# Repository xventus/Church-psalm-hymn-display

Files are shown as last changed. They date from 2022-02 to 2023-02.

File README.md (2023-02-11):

# Church psalm hymn display, display unit

Project for displaying hymn numbers and lyrics. This is the latest version and cheaper variant of the original FPGA VGA version. Solution based on a VGA LCD display and a remote keyboard with wireless / wired connection. Here are the complete resources including schematics and links to the modules. 

The old types of displays based on LED displays are compatible, the transmission protocol has not changed. 

# Číselník a zpěvník do kostelů

Jde o inovaci původní verze číselníku s LED i FPGA VGA zobrazovači. Protokol je zpětně kompatibilní. 
Zobrazovač je založen na VGA LCD monitoru a vzdáleného ovladače. Projekt je koncipován tak, aby jej byl schopen kdokoliv replikovat za pomocí dostupných modulů Arduino / ESP32 a nemusel vytvářet vlastní DPS.

VGA zobrazovač je založen na ESP32, konkretně levném modulu LILYGO® TTGO VGA32 V1.4  (s SD kartou)
http://www.lilygo.cn/prod_view.aspx?TypeId=50033&Id=1083

Klávesnici lze připojit buď lokálně přímo k TTGO VGA32 (PS/2), nebo přes vzdáleně přes RF modul, popřípadě RS485.
RF/RS modul se připojuje na PS/2 Mouse konektor Data (27).  

Vzdálená klávesnice je založena na ATMEGA328 v základním zapojení s 16MHz krystalem. Schéma a PCB design přiložen. Popřípadě lze použít jakékoliv Arduino. 
Oproti původní verzi nepoužívá modul MAX3421, ale využívá možnosti některých USB klávesnic pracovat v režimu PS/2. Pro zobrazení zadávaného čísla se používá modul LED displeje založený na TM1637. Pro bezdrátovou komunikaci lze využít modul APC 220. 

Kompatibilní klávesnice např. CONNECT IT NumCALC CKB-0060-BK
Nekompatibilní např. Genius NumPad i110

# Data pro SD kartu

Adresář scripts obsahuje pomocné programy pro převod žalmů a kancionálu do formátu pro VGA displej. 
Data z kancinálu byla získána stažením obsahu webu www.kancional.cz a převodem z html do vlastních dat. 
Texty žalmů jsou opisem z příšlušných knih. 

# Režimy zobrazení

V základním režimu zobrazovač nahrazuje tříciferný zobrazovač (000-996) s možností zobrazení slok (1-9).
Pokud má ESPšě modul připojenou SD kartu, lze zobrazovat žalmy, popřípadě i texty z kancionálu. 

Nastavemní viz. /doc/user-manual-csy.pdf 

# Licence

Volně k použití pro kostely, nekomerční účely ...

# Pár obrázků
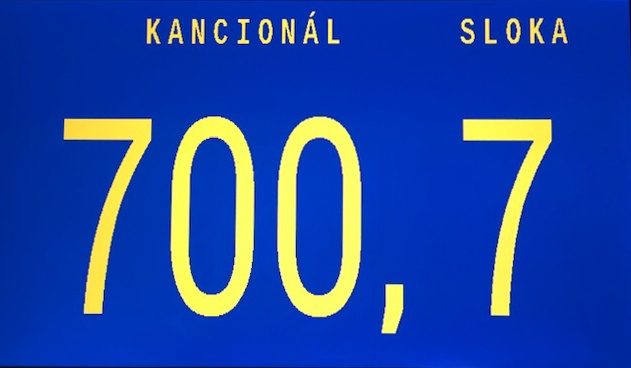
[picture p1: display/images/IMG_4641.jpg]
screen

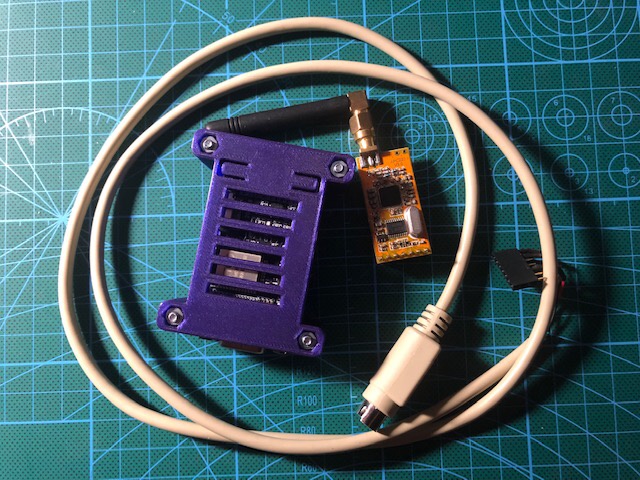
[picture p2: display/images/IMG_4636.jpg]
main board

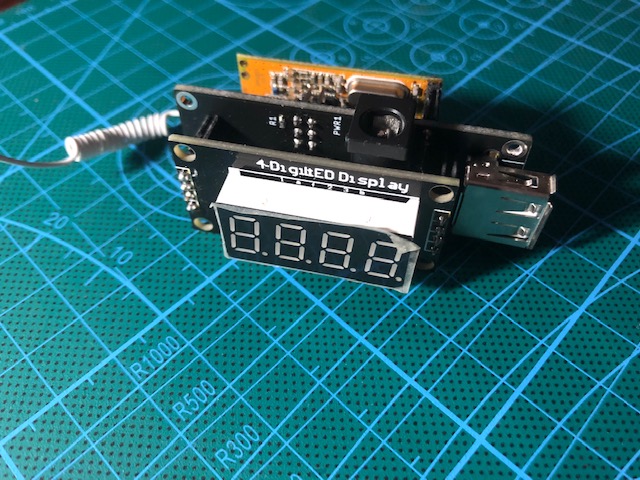
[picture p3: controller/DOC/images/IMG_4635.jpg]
remote

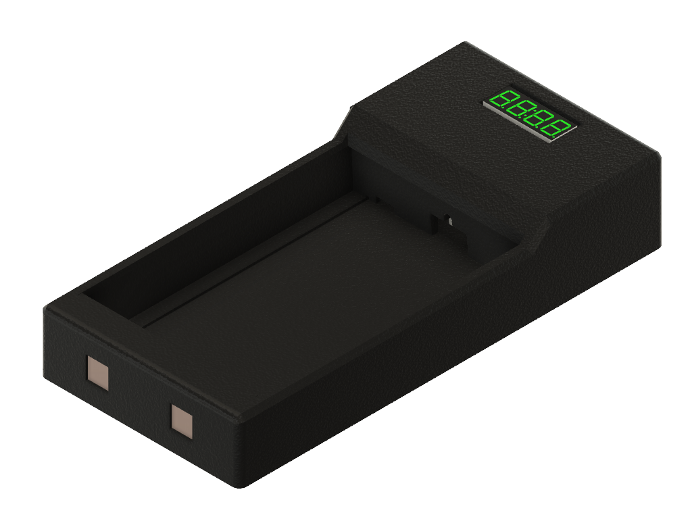
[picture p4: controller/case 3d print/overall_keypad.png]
case


# Nastavení knihoven
```
Platform espressif32 @ 6.0.1 (required: espressif32)
├── framework-arduinoespressif32 @ 3.20006.221224 (required: platformio/framework-arduinoespressif32 @ ~3.20006.0)
├── tool-esptoolpy @ 1.40400.0 (required: platformio/tool-esptoolpy @ ~1.40400.0)
├── tool-mkfatfs @ 2.0.1 (required: platformio/tool-mkfatfs @ ~2.0.0)
├── tool-mklittlefs @ 1.203.210628 (required: platformio/tool-mklittlefs @ ~1.203.0)
├── tool-mkspiffs @ 2.230.0 (required: platformio/tool-mkspiffs @ ~2.230.0)
├── tool-openocd-esp32 @ 2.1100.20220706 (required: platformio/tool-openocd-esp32 @ ~2.1100.0)
└── toolchain-xtensa-esp32 @ 8.4.0+2021r2-patch5 (required: espressif/toolchain-xtensa-esp32 @ 8.4.0+2021r2-patch5)

Libraries
└── FabGL @ 1.0.9 (required: fdivitto/FabGL @ ^1.0.9)
```

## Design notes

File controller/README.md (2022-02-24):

# controller

Remote control for the display. The controller is based on atmega328p. For its operation it requires a connected numeric keypad, which communicates via PS/2 and is connected to USB. Not all USB numeric keyboards can communicate this way. 

The DOC directory contains the schematic and STL for the box. 

Other libraries are used:

SevenSegmentTM1637 - see lib/SevenSegmentTM1637 for link and description.

PS2KeyAdvanced - see lib/PS2KeyAdvanced for link and description

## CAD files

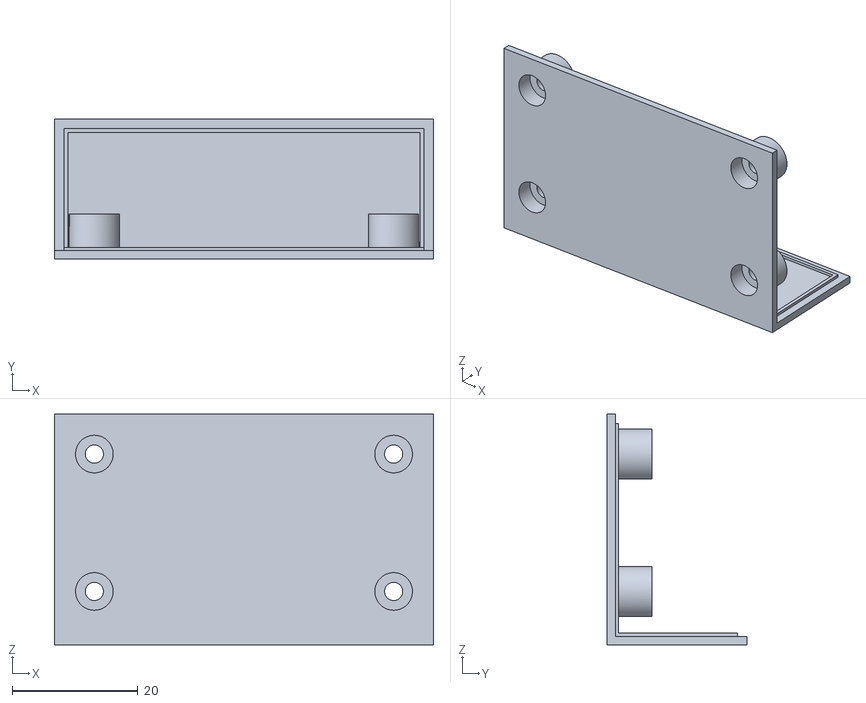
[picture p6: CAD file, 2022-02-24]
controller/case 3d print/charger_cover.stl
60.4 x 22.4 x 36.8

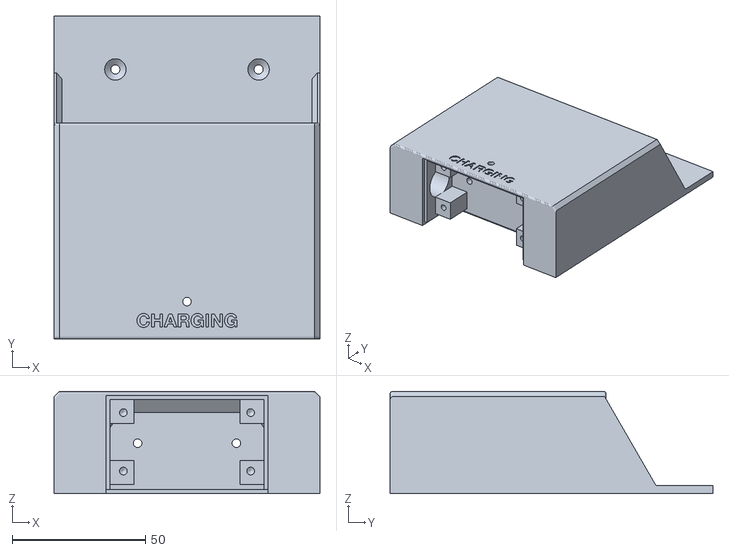
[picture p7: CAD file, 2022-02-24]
controller/case 3d print/charger_base.stl
99.7 x 121.0 x 38.4

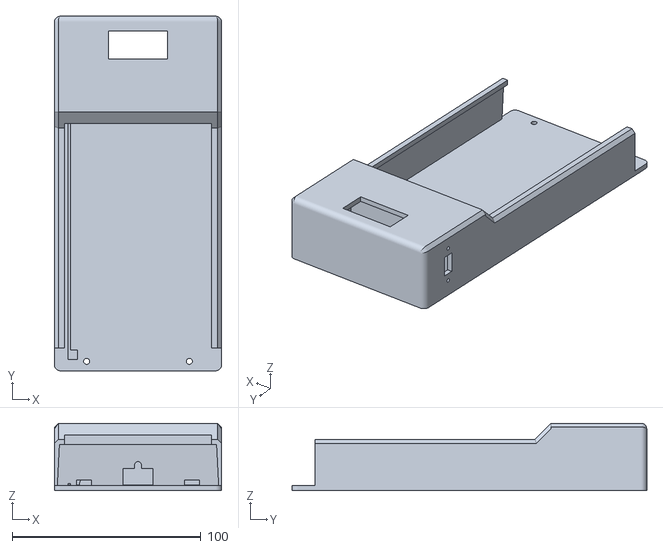
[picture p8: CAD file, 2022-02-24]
controller/case 3d print/Base.stl
88.4 x 187.7 x 35.7

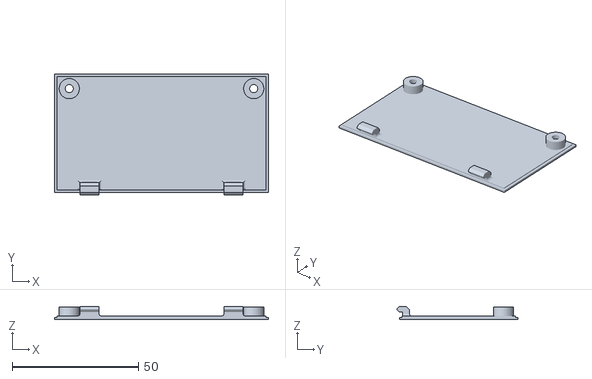
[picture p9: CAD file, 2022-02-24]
controller/case 3d print/Lid.stl
84.7 x 48.0 x 5.20

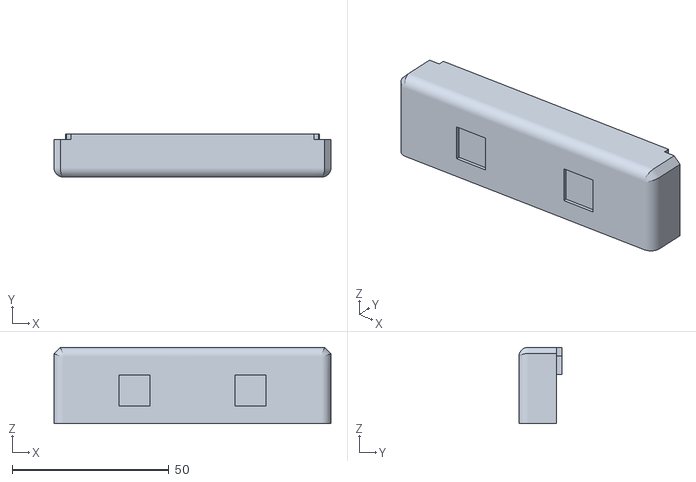
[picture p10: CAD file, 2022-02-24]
controller/case 3d print/Enclousure.stl
88.4 x 13.8 x 24.4

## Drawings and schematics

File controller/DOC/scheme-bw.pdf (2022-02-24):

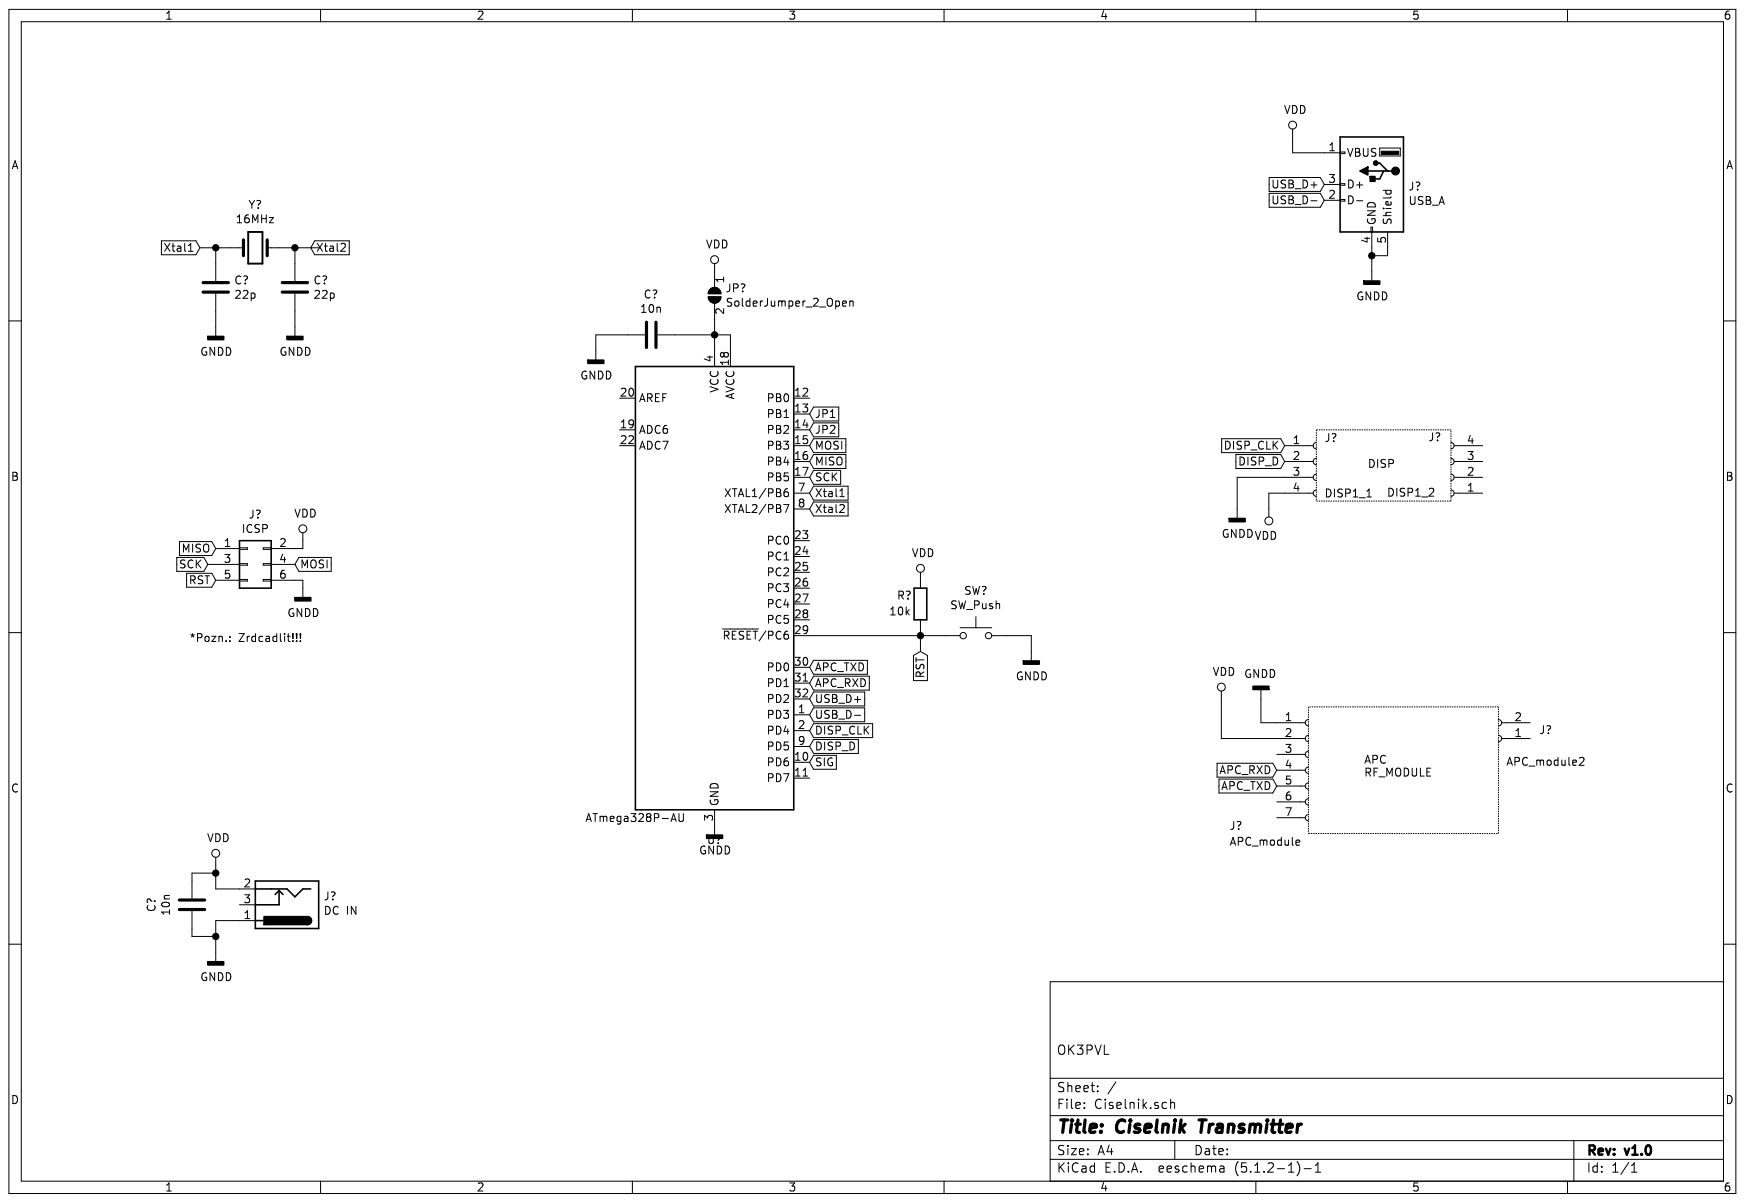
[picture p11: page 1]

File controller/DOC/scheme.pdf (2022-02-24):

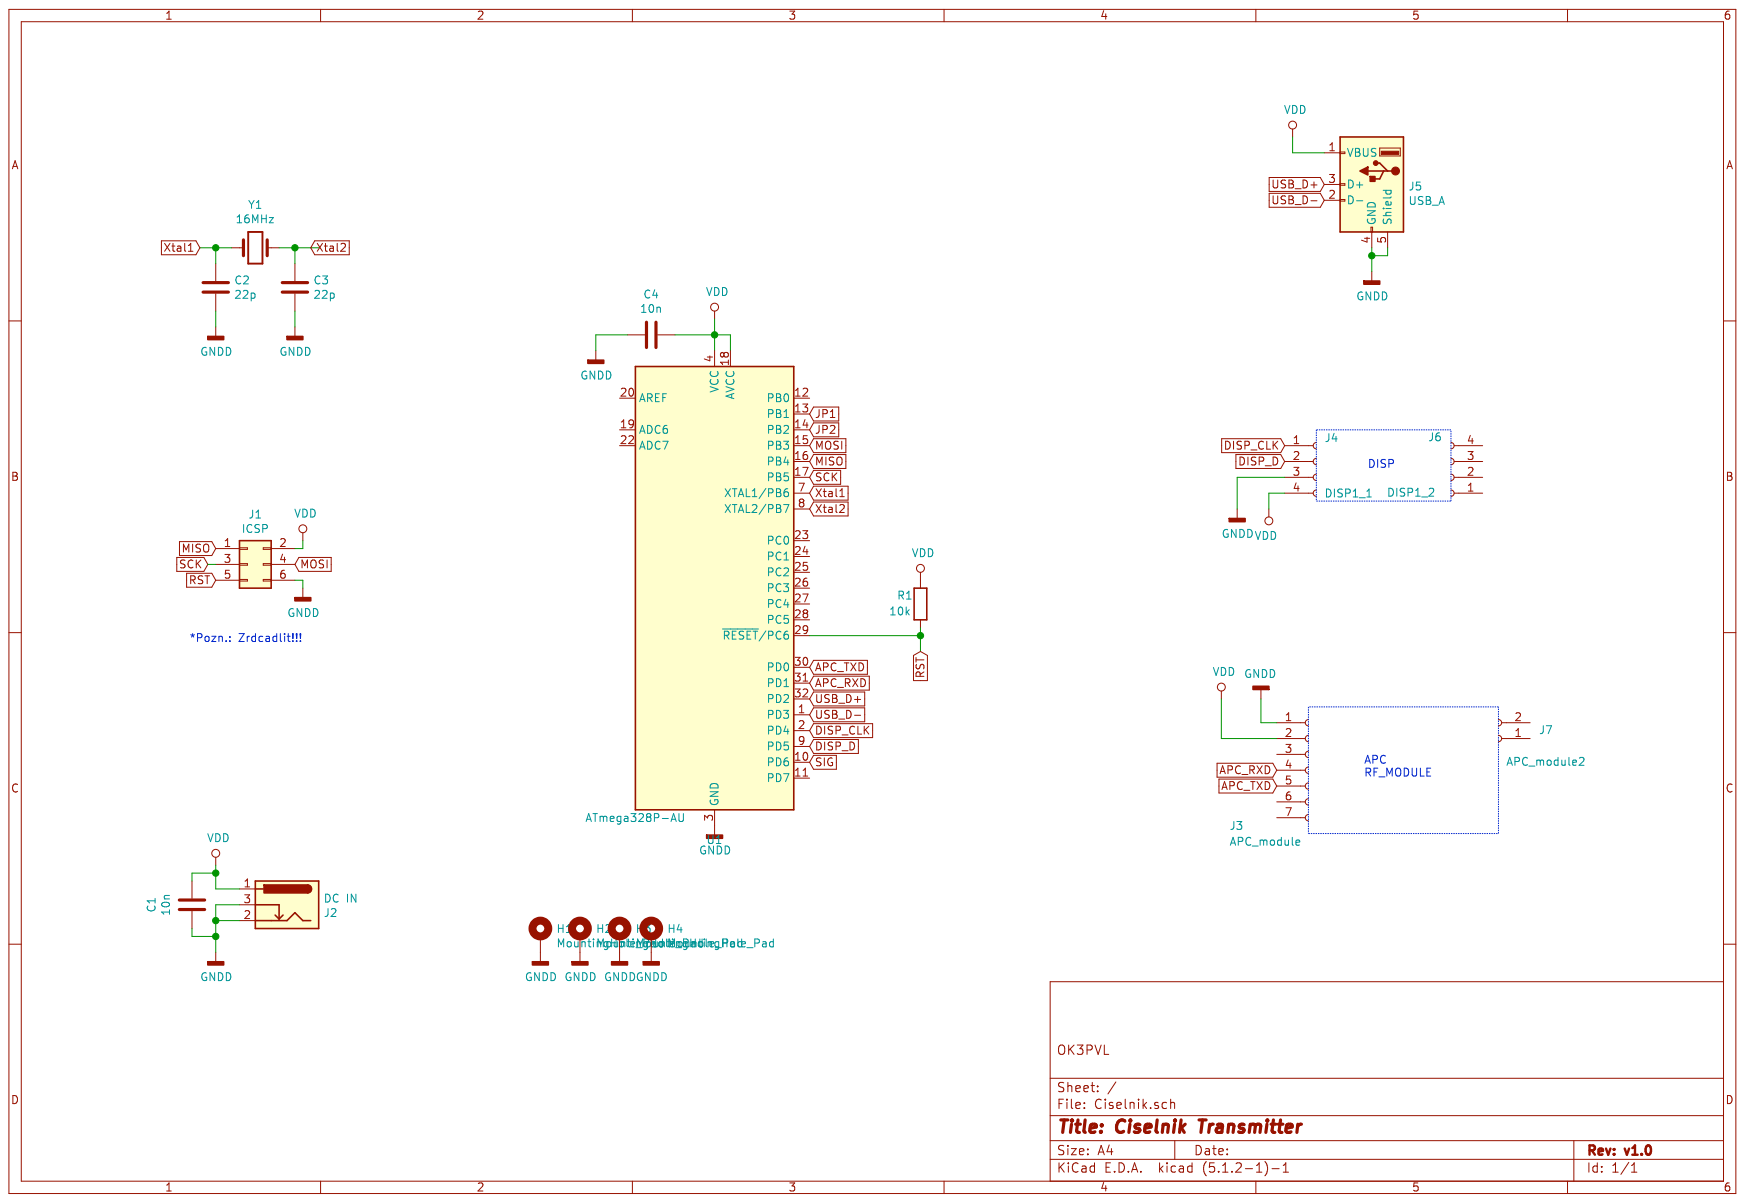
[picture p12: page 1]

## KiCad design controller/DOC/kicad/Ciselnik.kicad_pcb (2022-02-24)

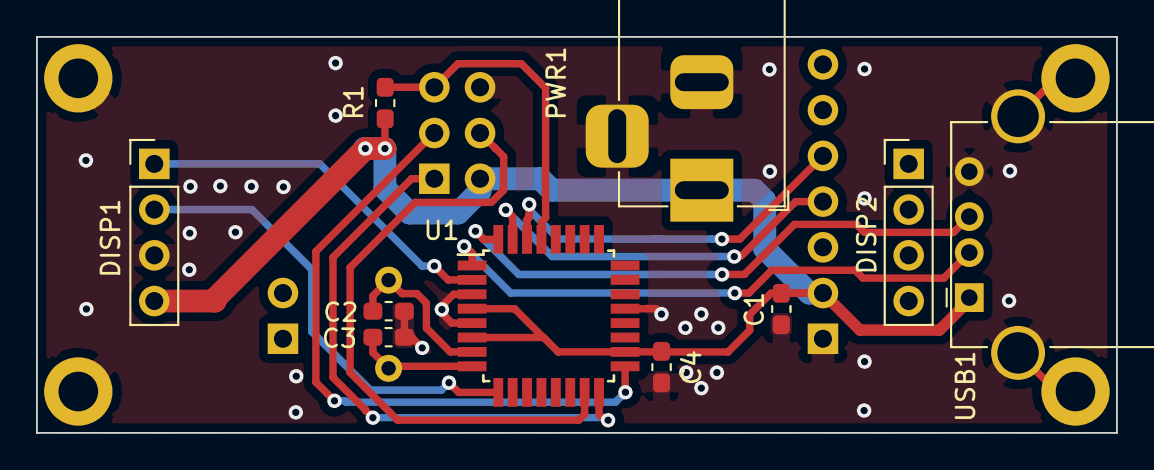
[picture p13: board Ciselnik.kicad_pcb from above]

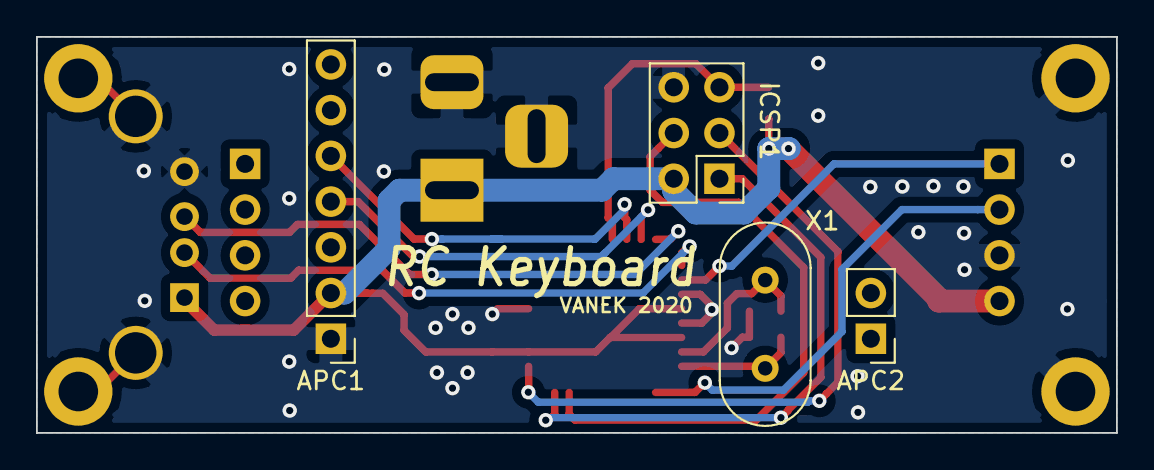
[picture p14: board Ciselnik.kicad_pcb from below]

Board: 2 copper layers, 60.0 x 22.0 mm, 18 parts (4 on the bottom side), 14 nets.

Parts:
APC1: APC_module; PinHeader_1x07_P2.54mm_Vertical
APC2: APC_module2; PinHeader_1x02_P2.54mm_Vertical
C1, C4: 10n; C_0603_1608Metric_Pad1.05x0.95mm_HandSolder
C2, C3: 22p; C_0603_1608Metric_Pad1.05x0.95mm_HandSolder
DISP1: DISP1_1; PinHeader_1x04_P2.54mm_Vertical
DISP2: DISP1_2; PinHeader_1x04_P2.54mm_Vertical
H1, H2, H3, H4: MountingHole_Pad; MountingHole_2.2mm_M2_DIN965_Pad
ICSP1: ICSP; PinHeader_2x03_P2.54mm_Vertical
PWR1: DC IN; BarrelJack_Horizontal
R1: 10k; R_0603_1608Metric_Pad1.05x0.95mm_HandSolder
U1: ATmega328P-AU; TQFP-32_7x7mm_P0.8mm
USB1: USB_A; USB_A_Stewart_SS-52100-001_Horizontal
X1: 16MHz; Crystal_HC18-U_Vertical

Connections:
APC_RXD: APC1.4, U1.31
APC_TXD: APC1.5, U1.30
DISP_CLK: DISP1.1, U1.2
DISP_D: DISP1.2, U1.9
GNDD: APC1.1, C1.1, C2.2, C3.2, C4.1, DISP1.3, H1.1, H2.1, H3.1, H4.1, ICSP1.6, PWR1.2, PWR1.3, U1.3, U1.5, U1.21, USB1.4, USB1.5
MISO: ICSP1.1, U1.16
MOSI: ICSP1.4, U1.15
RST: ICSP1.5, R1.1, U1.29
SCK: ICSP1.3, U1.17
USB_D+: U1.32, USB1.3
USB_D-: U1.1, USB1.2
VDD: APC1.2, C1.2, C4.2, DISP1.4, ICSP1.2, PWR1.1, R1.2, U1.4, U1.6, U1.18, USB1.1
Xtal1: C2.1, U1.7, X1.2
Xtal2: C3.1, U1.8, X1.1

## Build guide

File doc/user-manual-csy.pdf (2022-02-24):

# Číselník

Zobrazovač při zapnutí kontroluje obsah SD karty a zobrazí počet volných a obsazených mega bajtů karty, následně počet záznamů žalmu a záznamů z kancionálu. V případě, že karta je porušená nebo není vložená, napíše zobrazovač text "SD karta nenalezena". V takovém případě lze zobrazovat pouze čísla z kancionálu a žalmy nebo text z kancionálu není přístupný.
Po zobrazení konfigurace po 3 sekundách se zobrazí prázdná obrazovka s odkazem na farní stránky. Zobrazovač je připraven k příjmu zadávání údajů.
Zobrazovač může být nakonfigurován ve dvou režimech. Prvním z nich je zobrazování textu z kancionálu (pokud je uložen na SD kartě) a druhý je zobrazení pouze číselné informace. To, jaký režim je zapnut se zobrazí při startu zobrazovače ("Kancionál text: ZAPNUTO" nebo "Kancionál text: VYPNUTO").
Text z kancionálu v případě písně až po zadání čísla sloky. V případě modlitby se zobrazí ihned. Např. zadáme píseň 701 a stiskneme ENTER. Zobrazí se číslo písně z kancionálu. Pak stiskem "+" zobrazíme první sloku. Opakovaným stiskem zobrazujeme následné sloky, tak dlouho dokud jsou k dispozici. V případě, že žádná další sloka již není k dispozici, se zobrazí číslo písně a číslo sloky. Bez ohledu jaký režim je nastaven, číselník je ovládán stále stejně.

## Změna konfigurace zobrazovače

Při změně nastavení je nutné aby byly zapnuty všechny zobrazovače. Lze konfigurovat barevné schéma a nastavení zobrazování textu z kancionálu. Konfigurace je stále platná do další změny. Není ji potřeba při každém zapnutí provádět.

Klávesa | význam
0 - 9 | zadávání čísla z kancionálu nebo pořadového čísla žalmu
ENTER | odeslání čísla textu-písně z kancionálu na zobrazovač
/ (lomítko) | odeslání textu žalmu na zobrazovač
+ (plus) | sloka písně o jednu vpřed
- (mínus) | sloka písně o jednu vzad
* (hvězdička) | smazání zobrazovače
<- Backspace | smazání zadaných číslic bez odeslání (např. při chybném zadávání před odesláním)
. (tečka) | oddělovač sloky písně

Změn konfigurace se provádí odesláním čísel 999 a jako poslední číslo je nastavení konfigurace. Kód se nepotvrzuje pomocí ENTER. Při příjmu zobrazovač 3x za sebou zobrazí nastavenou konfiguraci a přejde do výchozího režimu pro příjem.

zadaný kód

9990 Kancionál text: VYPNUTO

9991 Kancionál text: ZAPNUTO

9992 Barevné schema 0, modré pozadí, žlutý text

9993 Barevné schema 1, černé pozadí, bílý text

9994 Barevné schema 2, bílé pozadí, černý text

9995 - 9999 | Vyhrazeno pro budoucí rozšíření

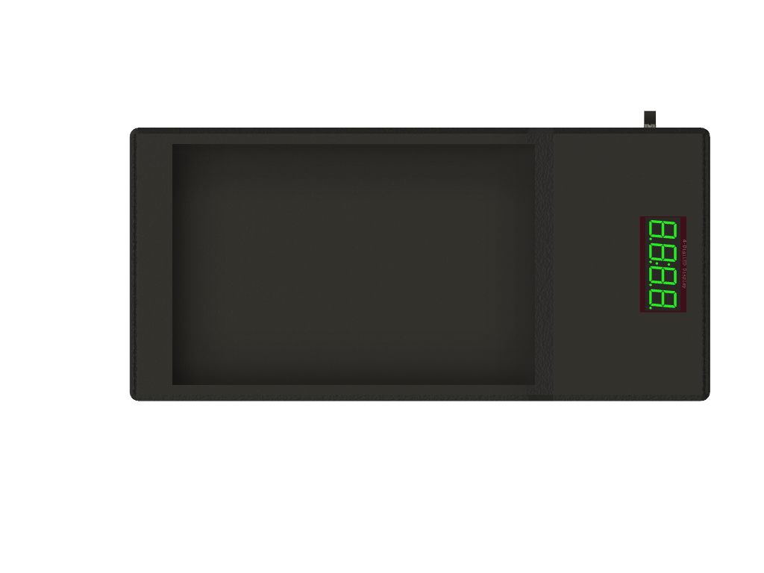
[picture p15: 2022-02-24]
controller/case 3d print/front.png

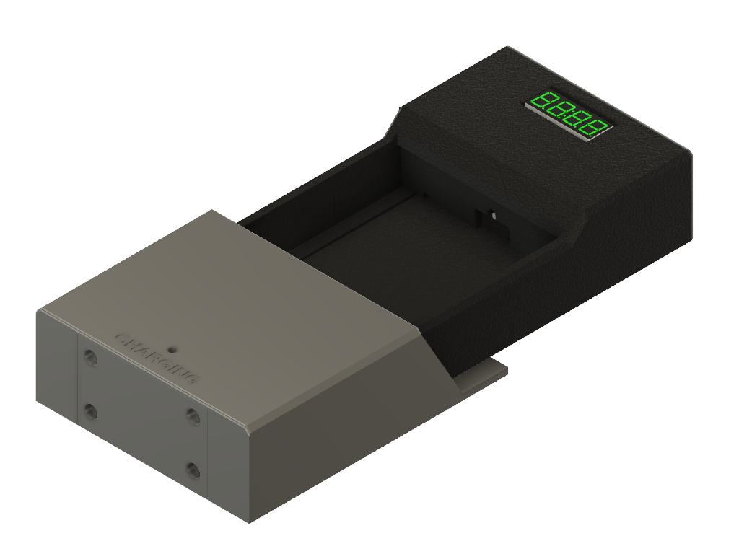
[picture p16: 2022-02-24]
controller/case 3d print/overall view.png

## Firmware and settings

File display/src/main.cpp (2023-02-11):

//
// vim: ts=4 et
// Church psalm hymn display, display unit
// Copyright (c) 2019 Petr Vanek, petr@fotoventus.cz
//
/// @file   main.cpp
/// @author Petr Vanek

/*
 based on board:  LILYGO® TTGO VGA32 V1.4 Controller PS/2 Mouse And Keyboard Graphics Library Game Engine And ANSI/VT Terminal For The ESP32
 Enviroment: ESP32 DEV Module
 L
 ibrary:   fabgle from http://www.fabglib.org/
*/

#include <stdio.h>

#include <fabgl.h>

#include "defs.h"          // constants and definitions
#include "configuration.h" // EEPROM config
#include "fonts.h"         // font glyphs
#include "net_buffer.h"    // buffer operations
#include "convertors.h"    // CSY char convertor, virtual keys to number
#include "strings_def.h"   // strings

// TODO: 
//  - move strings to program memory!!!
//  - divide the program into functional units
//  - fill in missing characters in the national alphabet

/************************************************/
// signletons

// VGA controller
fabgl::VGA16Controller VGAController;

// PS/2 keyboard as local controller
fabgl::PS2Controller PS2Controller;

// HW serial for APC220/RS485 - used only one WAY communication - RX used only
// used with remote controller via APC220 or RS485
HardwareSerial hwSerial_1(1);
NetBuffer nb;
Configuration conf;

//--------------------------------------------------------------------------------------------------------------------------------

/**
 * @brief display clear and set default color
 *
 */
void clear()
{
  Canvas cv(&VGAController);
  if (conf.getColorSchema() == 0)
  {
    cv.setPenColor(PENCOLOR);
    cv.setBrushColor(BRUSHCOLOR);
  }

  if (conf.getColorSchema() == 1)
  {
    cv.setPenColor(PENCOLOR_1);
    cv.setBrushColor(BRUSHCOLOR_1);
  }

  if (conf.getColorSchema() == 2)
  {
    cv.setPenColor(PENCOLOR_2);
    cv.setBrushColor(BRUSHCOLOR_2);
  }

  cv.clear();
}

//--------------------------------------------------------------------------------------------------------------------------------

/**
 * @brief display number at position
 *
 * @param x
 * @param y
 * @param number
 * @param fill
 */
void displayDigit(int x, int y, byte number, bool fill)
{
  Canvas cv(&VGAController);
  if (number > 10)
    return;
  cv.setGlyphOptions(GlyphOptions().FillBackground(fill).DoubleWidth(0));
  cv.drawGlyph(x, y, fontwidth, fontheight, &fontBB[0 + number][0]);
}

//--------------------------------------------------------------------------------------------------------------------------------

/**
 * @brief displays the glyph in the given size at the position
 * 
 * @param big  switches the size set 
 * @param x    position x
 * @param y    position y 
 * @param chr  desired character
 */
void displayChar(byte big, int x, int y, unsigned char chr)
{
  Canvas cv(&VGAController);
  auto decodedto = charConvertor(chr);

  if (big == 2)
  {
    cv.setGlyphOptions(GlyphOptions().FillBackground(false).DoubleWidth(1));
    cv.drawGlyph(leftsidetxt + x, topsidetxt + y, 24, 32, &fontB[decodedto][0]);
  }
  else if (big == 1)
  {
    cv.setGlyphOptions(GlyphOptions().FillBackground(false).DoubleWidth(2));
    cv.drawGlyph(leftsidetxt + x, topsidetxt + y, 24, 32, &fontB[decodedto][0]);
    cv.setGlyphOptions(GlyphOptions().FillBackground(false).DoubleWidth(3));
    cv.drawGlyph(leftsidetxt + x, topsidetxt + y + 32, 24, 32, &fontB[decodedto][0]);
  }
  else
  {
    cv.setGlyphOptions(GlyphOptions().FillBackground(false).DoubleWidth(0));
    cv.drawGlyph(leftsidetxt + x, topsidetxt + y, 24, 32, &fontB[decodedto][0]);
  }
}

//--------------------------------------------------------------------------------------------------------------------------------

/**
 * @brief prints a string at a given position in a given size
 * 
 * @param big switches the size set 
 * @param str string to print
 * @param pos 
 * @param yzero 
 * @param correction 
 * @return int 
 */
int printAtPos(byte big, const char *str, int pos, int yzero, bool correction)
{

  int x = pos;      // x possition of char
  int y = 0;        // y possiont of char
  int line = 0;     // line counter
  byte counter = 0; // char counter

  if (str == nullptr)
    return 0;
  Canvas cv(&VGAController);

  auto maxperline = (big == 1 || big == 2) ? (cv.getWidth() / (charwidthtxt * 2)) : (cv.getWidth() / charwidthtxt);
  auto linesperpage = (big == 1) ? (cv.getHeight() / (charheighttxt * 2)) : (cv.getHeight() / charheighttxt);
  if (big == 1) {
    linesperpage++;
  }
  counter = pos / (charwidthtxt + ((big == 1 || big == 2) ? charwidthtxt : 0));

  if (yzero != 0)
  {
    auto a = charheighttxt;
    a += ((big == 1) ? heightincrementcorrection : 0);
    y = a * yzero;
    linesperpage = linesperpage - yzero;
  }

  const char *st = str;
  auto cntline = (strlen(st) / maxperline) + 1;
  auto movy = charheighttxt;
  movy += ((big == 1) ? heightincrementcorrection : 0);
  auto ycorrection = (correction) ? ((linesperpage / cntline) * movy / cntline) : 0;
  if (cntline >= 7 && big == 2)
    ycorrection = 0;
  if (correction && cntline < 3)
  {
    // only y position of first line
    y += movy;
  }

  while (*st != 0)
  {

    if (*st == '\n')
    {
      // new line
      line++;
      x = 0;
      y += charheighttxt;
      y += ((big == 1) ? heightincrementcorrection : 0);
      counter = 0;
      st++;
      continue;
    }

    displayChar(big, x, y, *st);
    counter++;

    if (counter >= maxperline)
    {
      // move to next line if number of chars per line was exceeded
      line++;

      if (linesperpage <= line)
      {
        break;
      }

      // sets new position of char on the next line
      x = 0;
      y += charheighttxt;
      y += ((big == 1) ? heightincrementcorrection : 0);
      y += ycorrection;
      counter = 0;
    }
    else
    {
      x += charwidthtxt;
      x += ((big == 1 || big == 2) ? charwidthtxt : 0);
    }

    st++;
  }

  return x;
}

//--------------------------------------------------------------------------------------------------------------------------------

/**
 * @brief print from the begining
 * 
 * @param big 
 * @param str 
 * @param correction 
 */
void printAt(byte big, const char *str, bool correction)
{
   printAtPos(big, str, 0, 0, correction);
}

//--------------------------------------------------------------------------------------------------------------------------------

/**
 * @brief Printing the number
 * 
 * @param one 
 * @param two 
 * @param big 
 * @param str 
 * @param correction 
 */
void printAtWithNumber(int one, int two, byte big, const char *str, bool correction)
{
  String buffer;
  auto pos = 0;
  Canvas cv(&VGAController);
  if (one < 10)
    buffer = text_TWOZEROS;
  else if (one < 100)
    buffer = text_ZERO;
  buffer += String(one);

  cv.setPenColor(PENCOLOR2);
  pos = printAtPos(2, buffer.c_str(), 0, 0, false);
  if (two != 0)
  {
    pos = printAtPos(2, text_SLASH, pos, 0, false);
    buffer = String(two);
    pos = printAtPos(2, buffer.c_str(), pos, 0, false);
  }

  if (conf.getColorSchema() == 0)
  {
    cv.setPenColor(PENCOLOR);
  }

  if (conf.getColorSchema() == 1)
  {
    cv.setPenColor(PENCOLOR_1);
  }

  if (conf.getColorSchema() == 2)
  {
    cv.setPenColor(PENCOLOR_2);
  };
  printAtPos(big, str, 0, 1, true);
}

//--------------------------------------------------------------------------------------------------------------------------------

/**
 * @brief 
 * 
 * @param xp 
 * @param yp 
 * @param str 
 */
void printText(int xp, int yp, const char *str)
{

  int x = xp;       // x possition of char
  int y = yp;       // y possiont of char
  int line = 0;     // line counter
  byte counter = 0; // char counter

  if (str == nullptr)
    return;
  Canvas cv(&VGAController);

  auto maxperline = (cv.getWidth() / charwidthtxt);
  auto linesperpage = (cv.getHeight() / charheighttxt);

  const char *st = str;
  while (*st != 0)
  {
    displayChar(false, x, y, *st);
    counter++;

    if (counter >= maxperline)
    {
      // move to next line if number of chars per line was exceeded
      line++;

      if (linesperpage <= line)
      {
        break;
      }

      // sets new position of char on the next line
      x = xp;
      y += charheighttxt;
      counter = 0;
    }
    else
    {
      x += charwidthtxt;
    }

    st++;
  }
}

//--------------------------------------------------------------------------------------------------------------------------------

/**
 * @brief  display contnet of buffer - number type
 * 
 * @param buf 
 */
void displayNumberBuffer(uint8_t buf[])
{

  // with label
  bool b3digitonly = false;
  Canvas cv(&VGAController);
  cv.clear();

  if (buf[3] == 0)
    b3digitonly = true;

  auto movepos = cv.getWidth() / (((fontwidth + 10) * (b3digitonly) ? 3 : 4));
  auto toppos = (cv.getHeight() - fontheight) / 2;

  if (withlabel)
  {
    toppos += charheighttxt;
  }

  auto lleftside = 0;
  if (b3digitonly)
  {
    lleftside = cv.getWidth() - (3 * charwidth + (movepos / 2));
  }
  else
  {
    lleftside = cv.getWidth() - (4 * charwidth + (movepos / 2));
  }
  lleftside = lleftside / 2;

  auto xx = lleftside;

  for (int x = 0; x < 4; x++)
  {

    auto npositionvalue = buf[x];

    // filter uknown digit values
    if (npositionvalue > 9)
      continue;

    // shift left last digit
    if (!b3digitonly && x == 3)
    {
      xx += movepos / 2; // digitmovepos;
    }

    // hide last digit, when only 3 digits needs to be shown
    if (b3digitonly && x > 2)
      continue;

    // show number on desired position
    if (b3digitonly)
      displayDigit(xx + (x * (charwidth + (movepos / 3))), toppos, npositionvalue, true); // 3 digits only
    else
      displayDigit(xx + (x * charwidth), toppos, npositionvalue, true); // 4 digits with comma
  }

  if (!b3digitonly)
  {
    // add comma
    displayDigit(lleftside + (charwidth * 3), toppos, fontcomma, false);
    if (withlabel)
    {
      printText(lleftside + (charwidth * 3) + movepos / 2, 10, text_SLOKA);

      printText(lleftside + movepos / 2, 10, text_KANCIONAL);
    }
  }
  else
  {
    if (withlabel)
    {
      auto txtcenter = (cv.getWidth() / 2) - ((charwidthtxt * 9) / 2);
      
      printText(txtcenter, 10, text_KANCIONAL );
    }
  }
}
//--------------------------------------------------------------------------------------------------------------------------------

/**
 * @brief Welcome screen, displayed in case there is nothing to display
 * 
 */
void printHello()
{
  Canvas cv(&VGAController);
  cv.clear();
  auto txtcenter = (cv.getWidth() / 2) - ((charwidthtxt * 15) / 2);
  printText(txtcenter, cv.getHeight() - charheighttxt - 10, text_HELLO);
  auto h = cv.getHeight() - charheighttxt - 20;
  cv.drawLine(0, h, cv.getWidth() - 1, h);
}

//--------------------------------------------------------------------------------------------------------------------------------

/**
 * @brief the main display of the Psalm text
 * 
 * @param txt text to print
 */
void printPsalm(const char *txt)
{
  Canvas cv(&VGAController);
  cv.clear();
  printAtPos(2, text_PSALM, 0, 0, false);
  printAtPos(2, txt, 0, 2, true);
  auto h = charheighttxt + charheighttxt / 2;
  cv.drawLine(0, h, cv.getWidth() - 1, h);
}

//--------------------------------------------------------------------------------------------------------------------------------

/**
 * @brief initial system test, configuration and connected peripherals are displayed
 * 
 * @param sdcard 
 */
void initialTest(bool sdcard)
{
  String txt;
  int64_t total, used;

  if (sdcard)
  {
    FileBrowser::getFSInfo(fabgl::DriveType::SDCard, 0, &total, &used);

    txt += String(int(used / (1024 * 1024)));
    txt += text_START_1;
    txt += String(int((total - used) / (1024 * 1024)));
    txt += text_START_2; 

    auto dir = FileBrowser();
    dir.setDirectory(SDCARD_MOUNT_PATH);

    const auto psalmdir = text_psalms;
    const auto cancioaldir = text_hymns;
    dir.changeDirectory(psalmdir);
    auto t1 = dir.count() - 1;
    dir.setDirectory(SDCARD_MOUNT_PATH);
    dir.changeDirectory(cancioaldir);
    auto t2 = dir.count() - 1;

    txt += String(t1);
    txt += text_START_3; 
    txt += String(t2);
    txt += text_START_4;
  }
  else
  {
    txt += text_START_5;
  }
  txt += text_START_6; 
  txt += PS2Controller.keyboard()->isKeyboardAvailable() ? text_START_OK : text_START_NA;

  txt += text_START_7; 
  txt += (conf.getCantiMode()) ? text_ON : text_OFF;
  txt += text_START_8;
  txt += String(conf.getColorSchema());

  clear();
  printAt(false, txt.c_str(), false);
}
//--------------------------------------------------------------------------------------------------------------------------------

/**
 * @brief the text of the Psalm is loaded from the SD card
 * 
 * @param name - the name of the file whose content is loaded into the global `buffer`
 * @return true  - found & loaded 
 * @return false 
 */
bool loadPsalm(const char *name)
{

  char buffer[MAX_BUFFER_SIZE];
  memset(&buffer[0], 0, MAX_BUFFER_SIZE);

  bool rc = false;
  auto dir = FileBrowser();

  memset(&buffer[0], 0, MAX_BUFFER_SIZE);
  sprintf(buffer, "%s/%s", SDCARD_MOUNT_PATH, text_psalms);
  dir.setDirectory(buffer);
  rc = dir.exists(name, false);
  memset(&buffer[0], 0, MAX_BUFFER_SIZE);

  if (!rc)
  {
    return rc;
  }

  auto cnt = 0;
  auto fp = dir.openFile(name, text_rb_txt);
  if (fp)
  {
    char c;
    while ((c = getc(fp)) != EOF)
    {
      if (c == 255)
        break;
      buffer[cnt] = c;
      cnt++;
      if (cnt >= MAX_BUFFER_SIZE)
        break;
    }
  }
  fclose(fp);
  printPsalm(&buffer[0]);
  rc = true;
  return rc;
}

//--------------------------------------------------------------------------------------------------------------------------------

/**
 * @brief 
 * 
 * @param one 
 * @param two 
 * @param directory 
 * @param name 
 * @return true 
 * @return false 
 */
bool loadCancional(int one, int two, const char *directory, const char *name)
{
  char buffer[MAX_BUFFER_SIZE];
  bool rc = false;
  auto dir = FileBrowser();

  memset(&buffer[0], 0, MAX_BUFFER_SIZE);
  sprintf(buffer, "%s/%s/%s", SDCARD_MOUNT_PATH, text_hymns, directory);
  dir.setDirectory(buffer);
  rc = dir.exists(name, false);
  memset(&buffer[0], 0, MAX_BUFFER_SIZE);

  if (!rc)
  {
    return rc;
  }

  auto cnt = 0;
  auto fp = dir.openFile(name, text_rb_txt);
  if (fp)
  {
    char c;
    while ((c = getc(fp)) != EOF)
    {
      if (c == 255)
        break;
      buffer[cnt] = c;
      cnt++;
      if (cnt >= MAX_BUFFER_SIZE)
        break;
    }
  }
  else
  {
    rc = false;
  }
  fclose(fp);
  clear();
  printAtWithNumber(one, two, false, &buffer[0], true);
  rc = true;
  return rc;
}

//--------------------------------------------------------------------------------------------------------------------------------

/**
 * @brief error message display
 * 
 * @param message 
 */
void errorMessage(const char *message)
{
  clear();
  String txt;
  txt = text_ERROR;
  txt += message;
  printAt(0, txt.c_str(), false);
}

//--------------------------------------------------------------------------------------------------------------------------------

/**
 * @brief initializing the system and setting everything necessary
 * 
 */
void setup()
{
  conf.init();
  conf.refresh();
  Serial.begin(115200);

  hwSerial_1.begin(9600, SERIAL_8N1, APC220_RX1, APC220_TX1);

  // avoid garbage into the UART
  delay(500);

  VGAController.begin();
  VGAController.setResolution(VGAMODE);

  // PS/2 ony keyaboard
  PS2Controller.begin(PS2Preset::KeyboardPort0);

  // SD Card
  auto rc = FileBrowser::mountSDCard(FORMAT_ON_FAIL, SDCARD_MOUNT_PATH, 4, 16 * 1024, SD_MISO, SD_MOSI, SD_CLK, SD_CS);
  FileBrowser::setSDCardMaxFreqKHz(SDMMC_FREQ_DEFAULT);
  FileBrowser::remountSDCard();

  initialTest(rc);

  delay(5000);
  clear();
  printHello();
}

/**
 * @brief waiting on the keyboard - pressed key
 * 
 */
void keyboardWait()
{
  bool keyDown;
  auto keyboard = PS2Controller.keyboard();
  keyboard->getNextVirtualKey(&keyDown);
  while (keyDown)
  {
    keyboard->getNextVirtualKey(&keyDown);
  }
}

/**
 * @brief returns the value of the press key from the keyboard 
 * 
 * @return int 
 */
int keyboardupdate()
{

  if (!PS2Controller.keyboard()->isKeyboardAvailable())
  {
    return -1; // fabgl::VirtualKey::VK_NONE ;
  }

  bool keyDown;
  auto keyboard = PS2Controller.keyboard();
  VirtualKey vk = keyboard->getNextVirtualKey(&keyDown);
  return virtualKeyToNumber(vk);
}

/**
 * @brief main loop, running around until you lose your mind 
 * 
 * TODO:  eventually divide this toilet paper into separate functions
 */
void loop()
{


  bool changed = false;
  auto kbd = keyboardupdate();

  if (kbd > -1)
  {
    nb.addByteToParse(kbd);
    keyboardWait();
  }

  if (hwSerial_1.available())
  {
    auto c = hwSerial_1.read();
    nb.addByteToParse(c);
  }

  if (nb.isChanged())
  { 
    nb.cancelChange();
    if (nb.isHello())
    {
      clear();
      printHello();
    }
    else if (nb.isNumber())
    {

      /*detect configuration message 999 */
      if (   nb.getBuffer()[0] == 9 
          && nb.getBuffer()[1] == 9 
          && nb.getBuffer()[2] == 9)
      {

        if (nb.getBuffer()[3] == 0)
        {
          conf.setCantiMode(0);
          changed = true;
        }
        if (nb.getBuffer()[3] == 1)
        {
          conf.setCantiMode(1);
          changed = true;
        }

        if (nb.getBuffer()[3] == 2)
        {
          conf.setColorSchema(0);
          changed = true;
        }

        if (nb.getBuffer()[3] == 3)
        {
          conf.setColorSchema(1);
          changed = true;
        }

        if (nb.getBuffer()[3] == 4)
        {
          conf.setColorSchema(2);
          changed = true;
        }

        if (changed)
        {
          initialTest(true);
          delay(3000);

          nb.seyHello();
          clear();
          printHello();
          return;
        }
      }

      if (conf.getCantiMode() != 0)
      {

        String fileString;
        String dirString;
        dirString += (char)(nb.getBuffer()[0] + 48);
        dirString += (char)(nb.getBuffer()[1] + 48);
        dirString += (char)(nb.getBuffer()[2] + 48);

        fileString += (char)(nb.getBuffer()[3] + 48);
        fileString += text_file_txt;
        int one = nb.getBuffer()[0] * 100 + nb.getBuffer()[1] * 10 + nb.getBuffer()[2] * 1;
        int two = nb.getBuffer()[3];
        auto isOK = loadCancional(one, two, (char *)dirString.c_str(), (char *)fileString.c_str());
        if (!isOK)
        {
          displayNumberBuffer(nb.getBuffer());
        }
      }
      else
      {
        // only numeric mode
        displayNumberBuffer(nb.getBuffer());
      }
    }
    else if (nb.isText())
    {
      String fileString;
      fileString += (char)nb.getBuffer()[0];
      fileString += (char)nb.getBuffer()[1];
      fileString += (char)nb.getBuffer()[2];
      fileString += text_file_txt;
      auto isOK = loadPsalm((char *)fileString.c_str());
      if (!isOK)
      {
        fileString += text_NOTFOUND;
        errorMessage(fileString.c_str());
      }
    }
  }
}

/*EOF*/

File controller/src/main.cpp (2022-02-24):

//
// vim: ts=4 et
// Church psalm hymn display, remote keyboard
// Copyright (c) 2019 Vanek
//
/// @file   main.cpp
/// @author Petr Vanek

/*
 *  Board based on ATmega328, 16MHz
 *
 *  PS/2 keyboard via USB
 *  TM1637 - 4 digits display
 *  APC220 as TX link
 *
 */


#include <Arduino.h>
#include <PS2KeyAdvanced.h>
#include <SevenSegmentTM1637.h>
#include "buffer.h"

 // display based on TM1637
#define DISPLAY_CLK 4 
#define DISPLAY_DIO 5
SevenSegmentTM1637    display(DISPLAY_CLK, DISPLAY_DIO);

// PS2 numeric key pad, or USB with PS/2 support
#define PS2_DATA  3  // D- 
#define PS2_IRQ   2  // D+
PS2KeyAdvanced keyboard;

// data buffer
Buff buff;

// predefined texts
const char text_init[] PROGMEM  = "init\0";
const char text_rdy[]  PROGMEM  = "rdy \0";
const char text_err1[] PROGMEM  = "Err1\0";
const char text_err2[] PROGMEM  = "Err2\0";

//  implementation

/**
 * @brief deletes the local display, displays a dot as a power indicator 
 * 
 */
void clearD() {
  display.printRaw((uint8_t)0, (uint8_t)0);
  display.printRaw((uint8_t)0, (uint8_t)1);
  display.printRaw((uint8_t)0, (uint8_t)2);
  display.printRaw((uint8_t)128, (uint8_t)3); 
}

/**
 * @brief digit display on LED
 * 
 * @param pos - position of the displayed character
 * @param value - numeric or ASCII value of the number
 * @param dot - show decimal point as separator
 * @param show - show or turn off position
 */
void showNumber(uint8_t pos, uint8_t value, bool dot, bool show) {

  if (!show) {
    display.printRaw((uint8_t)0, pos);
  }
  else {
    uint8_t dsp = 0;
    if (value > 9) {
      dsp = display.encode((char)(value));
    }
    else {
      dsp = display.encode((char)(value + 48));
    }
    if (dot) dsp += 128;
    display.printRaw(dsp, pos);
  }
}

/**
 * @brief display of the entered number
 * 
 * @param curspos - position of the entered number
 */
void displayD(uint8_t curspos) {
 
  auto zerocnt = 0;
 
  for (auto o = 0; o < MAX_DIGIT; o++) {
    auto cn = buff.getNumber(o);
    if (cn == 0 || cn == 48) {
      zerocnt++;
    }
    else {
      break;
    }
  }

  if ((zerocnt == MAX_DIGIT && curspos == MAX_DIGIT) || curspos == 0) {
    clearD();
    return;
  }

  auto cn = buff.getNumber(MAX_DIGIT - 1);
  if (cn == 0 || cn == 48) {
    showNumber(0, 0, false, false);
  }

  for (auto i = 0; i < MAX_DIGIT; i++) {

    if (curspos == MAX_DIGIT) {
      // show all
      auto con = buff.getNumber(MAX_DIGIT - 1);
      if (con == 0 || con == 48) {
        // last position is zero - do not display it
        showNumber(i + 1, buff.getNumber(i), false, true);
      }
      else {
        showNumber(i, buff.getNumber(i), (i == MAX_DIGIT - 2) ? true : false, true);
      }
    }
    else {
      // moving position
      /*
         pos = 1 -->  disp 3 from buffer 0
         pos = 2 -->  disp 3 from buffer 1, disp 2 from buffer 0
         pos = 3 -->  disp 3 from buffer 2, disp 2 from buffer 1, disp 1 from buffer 0
      */
      showNumber((MAX_DIGIT - 1) - i, buff.getNumber(curspos - 1 - i), false, true);
      if (curspos == (i + 1)) break;
    }
  }
  
}


/**
 * @brief default settings & program start
 * 
 */
void setup() {
 
  // initialization of the LED display
  display.begin();
  display.setBacklight(100);
  display.print(text_init);

  // initialization of the serial line for RF communication, optionally for RS 485
  Serial.begin(9600);

  // PS2 / USB keyboard initialisation
  keyboard.begin(PS2_DATA, PS2_IRQ);
  delay(1000);
  keyboard.echo();              // ping keyboard to see if there
  delay(6);
  auto c = keyboard.read();
  if ((c & 0xFF) == PS2_KEY_ECHO
    || (c & 0xFF) == PS2_KEY_BAT) {
    display.print(text_rdy);   // keyboard found, display "rdy"
    }
  else
    if ((c & 0xFF) == 0) {
      display.print(text_err1); // the keyboard response is 0, not ready? "Err1" is displayed
    }
    else
    {
      display.print(text_err2); // unsupported answer, "Err2" is displayed
    }

  buff.clear();
  delay(500);
  clearD();
  keyboard.setLock(PS2_LOCK_NUM);
}



/**
 * @brief Repeat till you're blue in the face  ;-)
 * 
 */
void loop() {

  // prevent to switch numeric off
  if (!(keyboard.getLock() && PS2_LOCK_NUM)) {
    keyboard.setLock(PS2_LOCK_NUM);
  }


  if (keyboard.available()) {
    // read the next key
    auto c = keyboard.read();
    if (buff.push(c)) {
      auto status = c >> 8;
      // continuous display result

      if (buff.isExec()) {
        displayD(buff.getCursorPos());
        
        // send data to the remote display
        // Here there is no sophisticated way of checking errors during 
        // transmission and for compatibility with old displays the sequence 
        // of numbers is sent several times over. The receiver then accepts 
        // two consecutive sequences as legitimate data. 
        // Something like CRC would be useful in the future, but there is no time.  

        for (uint8_t c = 0;c < 3;c++) {
          for (uint8_t b = 0;b < MAX_DIGIT;b++) {
            Serial.write((uint8_t)buff.getNumber(b));  // Here the characters are sent over the serial line. 
          }
          delay(40);
        }

        buff.copyToShadow();
      }
      else {
        if (buff.getCursorPos() == 1) {
          clearD();
        }

        displayD(buff.getCursorPos());
      }

      // wait for release key
      while (true) {
        c = keyboard.read();
        if ((c >> 8) != status) break;
      }

    }
  }
}

/*EOF*/

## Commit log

2022-02-24 free version - VGA ESP32 based
    VGA version
    [Ciselnik.kicad_pcb, Ciselnik.sch, configuration.h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]
2022-02-24 case for keyboard & controller
    [Base.stl, Enclousure.stl, Lid.stl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]
2023-02-11 update fdivitto/FabGL@^1.0.9 and switch color from red to white
